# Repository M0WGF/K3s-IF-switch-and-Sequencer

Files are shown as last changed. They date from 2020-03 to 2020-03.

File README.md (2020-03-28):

# K3/s IF switch and Sequencer
Two port IF switch and three event sequencer for use with the Elecraft K3 and K3s transceivers. 

Switch between two external transverters directly from the Elecraft K3/s transceiver, the unit also comes with a three
port sequencer where the first event is for switching a relay and the last two events pull to ground.

The unit is based around an Arduino UNO see the .ino file for the script, it uses one no standard library which is
called Bounce2 and be downloaded from https://github.com/thomasfredericks/Bounce2

The unit has also been designed so that when the VSWR trip is pulled to ground the unit goes into a disabled state
stopping the transmitter and sounding a buzzer until the unit is reset. 

There are two boards the main board and an indicator board.  

The software has few parameters that can be changed look towards the top of the .ino file these are

// Event Sequence Delays 

int Sequence_Delay = 50; // Delay in milliseconds.
int Txinhibit_Delay = 50; 

// Default RX behaviour of events HIGH = On; LOW = Off.   Event 1 is capable of providing upto 28V 1A, and by default is 
set to energise the relay for RX.

int band0_event1 = HIGH;
int band0_event2 = LOW;
int band0_event3 = LOW;

int band1_event1 = HIGH;
int band1_event2 = LOW;
int band1_event3 = LOW;

// Debugging will output the debugs to the serial port. 
bool debug_main = false;

For further details see : 
https://m0wgf.blogspot.com/2019/12/dual-transverter-if-switch-and.html

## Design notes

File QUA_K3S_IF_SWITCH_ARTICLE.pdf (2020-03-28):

## A simple dual transverter IF switch and sequencers for the

Elecra9 K3S.

By Mark Horn M0WGF.
Interests in radio.

My main interest in amateur radio is in Earth-Moon-Earth (EME), Meteor Sca?er (MS), Machine Generated Modes(MGM) and the UKAC (UK Activity Contest) primarily on the 2m band as well as the 70cm band.

Consequently over the past few years I have been a?empting to build a high performance station built using a G4DDK transverters along with a HF transceiver to give the best performance I can afford on my budget.
Overview.

I have a medical condition called Muscular Dystrophy which results in the muscles of body slowly atrophying over Dme which has resulted in my hand muscles weakening to the point I struggle connecting and disconnecting any type of RF connector; this poses a problem in that I use transverters for my 2m and 70cm systems and constantly need to swap the 28MHz IF lines.

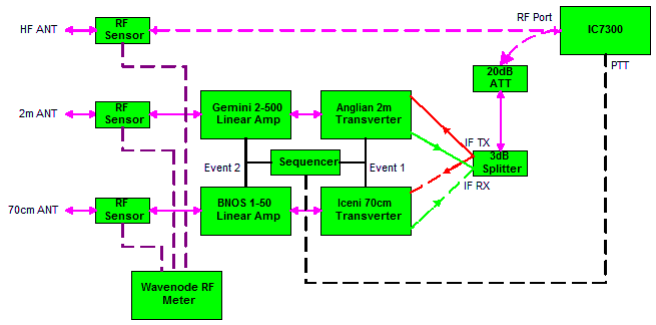
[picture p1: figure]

The original station configuration had the disadvantage in that the IF lines between the radio and transverter would need switching between transverters each Dme I wished change from 2m to 70cm. I also needed to unplug the HF antenna from the IC7300 and instead connect a 20dB a?enuator and 3dB spli?er to reduce the RF power down to around 0dBm and provide the RX / TX IF lines required by the transverter. Consequently each Dme I wanted to switch between either the transverters or the HF bands it felt like a major station configuration change.

Another issue with the IC7300 was geting a modulation that was free of spurii, this wasn’t an issue when using the transceiver on HF at 100W but when coupled with a transverter and high power amplifier the spurii in the adjacent 3kHz bandwidth or wider could be less than 40dB down in relation to the peak output.

I tried resolving this by using a modification by Kuhne electronics in Germany which places a small circuit board consisting of a couple of relays between the exciter and internal PA to provide TX and RX IF lines however the quality of modulation was still poor.

The main cause seems to be in the way Icom has implemented the ALC and acer reading reports from other operators it was apparent that geting the IC7300 to play nicely with any transverter varies from one IC7300 to another.

A station sequencer is employed to ensure any pre-amps are switched out of the TX signal path as well as to ensure hot switching doesn’t occur to any relays in said path before any RF is generated by the exciter by placing the exciter as the last event in the sequence.

The current setup used a single sequencer shared between the transverters and other devices though this was perfectly adequate I wanted the new system to use separate sequences where each event could be configured or at least modified at a later date without too much issue. It would also help if there was any RF leakage between adjacent relay contacts in the proposed IF switch wouldn’t be broadcast on the inactive band.

Both of my transverters where built with a single RF port with an internal relay to switch the port between the RX and TX ports on the transverter module however this isn’t ideal.

With EME we are dealing with path losses of around 250dB and as such the received signal is extremely weak so much so that you need to gain every decibel of receive performance you can, especially in a small system, even the losses incurred in multiple connectors and relays in the RX path can cause a dB or more of loss, with this in mind I also decided to modify both my transverters to provided a separate RX and TX RF ports.

The station also utilises an Wavenode RF power meter to monitor in real Dme the VSWR of each antenna. In the event of a high VSWR the Wavenode closes an internal relay this can used to connect to an external monitor to cease operation of the station.

So with the above in mind I decided to completely re-engineer the station to give the best receive and transmit performance I could get on the 2m and 70cm bands, reduce the amount of cable swapping and have separate sequencers for each of the transverters.

To cure the poor quality of the generated signal from the IC7300 I decided to sell it and instead purchase an Elecrac K3S (K3) instead.

The K3 helpfully provides both RX and TX IF ports with the TX port output at 0dBm giving the correct level of drive for the transverters.
A New Approach.

Upon reading the K3 manual I discovered the ACC port provides four TTL level, low (0V) or high (5V), logic gates where a combination of the four indicates which band is currently selected.

The ACC port can also provide PTT and TX inhibit functions again via two logic gates which would also reduce the amount of cabling required as well as ensure the all devices in the TX chain had switched fully before any RF is generated and vice versa for the RX chain.

The ACC port consists of a DE-15 socket where pins 3, 9, 13 and 14 provide access to the TTL logic gates and pins 7 and 10 provide the TX inhibit (TXINHIB), which can be configured to inhibit the exciter on either a high or low state, and KEYOUT-LP (PTT) which provides a 10mA sink to ground.

This was exactly what I needed to create a single control unit to switch IF lines, provide an independent sequencer to each transverter chain and to ensure that no RF was generated until all events in each sequence was completed all at the press of the band selector bu?on on the K3 acer some thought I came up with the following station configuration.

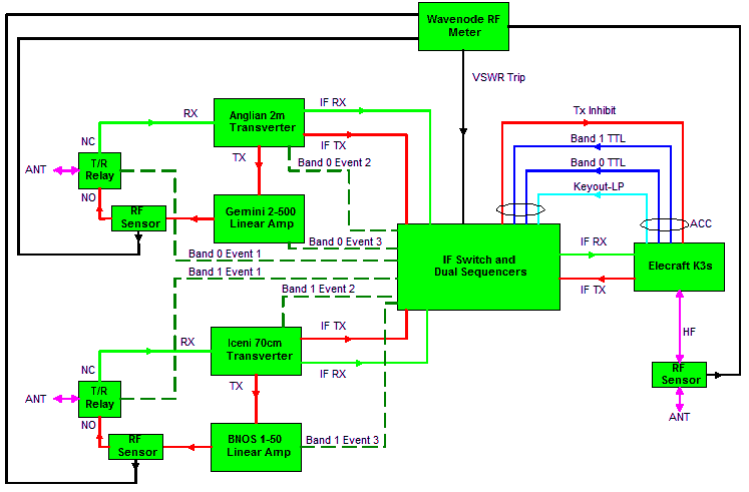
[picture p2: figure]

Hardware Configuration.

The K3s band logic gates can be configured in one of three ways NOR for HF bands only, TRN for transverters only and HF-TRN for both the HF bands and transverters. I selected the TRN seting which made reading the TTL logic simpler as it only requires knowing the current state of two of the logic gates instead of the four gates required for the NOR or HF-TRN configurations.

From here on forward when I reference bands it is taken to also include the transverters.

The band switch logic matrix for the K3 is shown lec.

As you can see from the table when TRN1 or TRN2 is selected the logic can either be on off for either band but they can neither be off or on together for band 0 and 1 so any other state would be equal to another band.

So with the above in mind I needed firstly someway to read the K3 TTL logic.

Secondly to key the 2m and 70cm transverters as well as associated amplifiers a 10mA sink to ground.

Thirdly the change over relays, Tohtsu CZX-3500, which require 12V and draw around 250mA, which would be held closed for RX operation and released for TX. The CZX-3500’s also have an advantage or providing an extra 20dB of isolation between ports compared to the ones in the transverters which only provided 40dB of isolation.

Fourthly the ability to control two mini relays to switch the IF lines between transverters.

Fichly It would also be useful to have some indication of which band has been selected as a separate confirmation to the K3, and that events for that band are being sequenced correctly.

Finally it would be nice to have some kind of audible alert in the event of a high VSWR.

ADDR | BAND0 | BAND1 | BAND2 | BAND3
TRN1 | 1 | 0 | 0 | 0
TRN2 | 0 | 1 | 0 | 0
TRN3 | 1 | 1 | 0 | 0
TRN4 | 0 | 0 | 1 | 0

Hardware and So9ware.

Thinking about how to go about accomplishing this I came to the conclusion using an Arduino microcontroller would be the easiest route to geting something working fairly quickly with li?le expense as well as keeping the electronics side of things simple.

The advantages using an Arduino :

1. Native ability to read the TTL logic from the K3.
2. General purpose I/O pins capable of providing or sinking 5V at 20mA.
3. Each I/O pin is protected from under and over voltage conditions using clamping diodes.

The Arduino UNO uses an ATMega328P which has 23 general purpose digital I/O pins available however two are used for serial coms and one for a reset bu?on, two pins are used for an external 16MHz crystal, so minus those five I/O pins eighteen pins are available to for other purposes.

I decided I need the following pins:

2 pins to read the band switch TTL logic from the K3.
3 pins to light LED’s to indicate which band has been selected on the unit. 2 pins for the IF relays.
1 pin to monitor PTT enabled from the K3.
1 pin for a PTT LED indicator.
1 pin to enable and disable TX Inhibit function on the K3.
1 pin to monitor the VSWR trip alert from the Wavenode RF power meter.
1 pin for the VSWR trip enabled warning buzzer.
1 pin for a VSWR trip reset bu?on, for which I’ll use the default Arduino reset pin. 6 pins for the two sets of three for the sequencer, one set for each band selected.

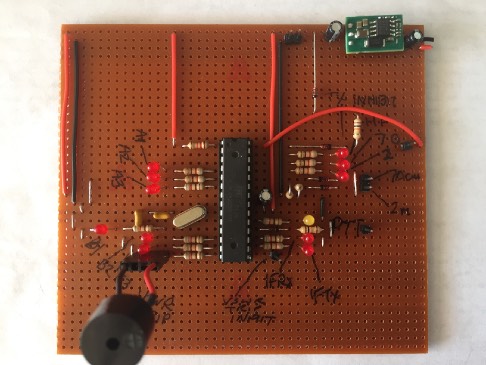
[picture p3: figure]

The first thing I did was to create a small prototype
board so I could write the socware and check
everything worked with the K3 before moving on to the
proper electronics, the purpose of the prototype board was to read the K3 TTL logic, show the state of the IF relays and sequencers using LED’s to indicate there current state as well test the TX inhibit function on the K3.

As is always the way with these things, having a shack that looks like a small nuke has gone off, I couldn’t find my breadboard to so had to make a test rig including an ATMega328 using some strip board instead this is also had the advantage that once it was wired up no amount
of moving it around on the desk the wiring will stay
error free.

Programming the Arduino is fairly straight forwarding using the Arduino IDE from the Arduino website¹. The language used is a subset of the C/C++ language which is fairly simple to use and there are plenty of resources on the internet to get you started.

The first iteration of the socware was a simple loop that read the state of the I/O pins that monitor the band logic gates on the K3 and lit an LED to indicate which transverter / band was selected.

What became apparent with this first simple loop was despite the fact there isn’t any mechanical switches the socware was experiencing contact bounce, also known as cha?er or bu?on bounce, seen in this instance as the wrong LED being lit for the band selected.

Contact bounce² is caused when a switch is pressed or released and for a few milliseconds or more the switch state is unstable to get around this problem it is normal to get the state of the I/O pin and store it in variable and then wait for a defined period and check

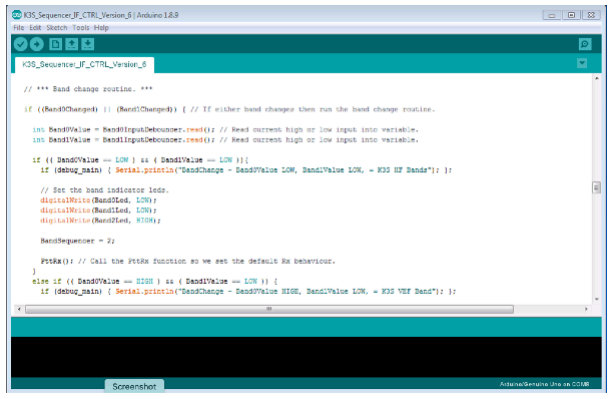
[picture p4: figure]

again when the stored state and current state are equal we can be sure the switch is either high or low.

There was two issues caused by contact bounce, one if the Arduino was switched on before the K3 then the band selected on the Arduino may not be in agreement with the band selected on the K3 and secondly when the band was changed on the K3 occasionally the wrong band was detected.

To resolve for these issues I started writing my own routine to take into account the unstable state of the switch while bouncing but in a sudden moment of genius decided not to reinvent the wheel and instead download and installed a library called Bounce2.h³ which reduced the amount of code I had to write for myself.

With the contact bounce cured it took an evening to write the socware⁴ and that included having to remind myself how hardware is referenced on the Arduino, the web is great for these kinds of projects there’s always plenty of example code around if you’re unsure how to do something.

With the socware wri?en the next thing to do was get on with the hardware, now electronics isn’t my forte so this wasn’t something I was looking forward too.

I knew for sequence events two and three some simple NPN transistors in low side configuration would suffice however for event one I needed the ability to switch between 5V to 48V drawing up to 1A, so that in the event I need to replace the change over relays I wouldn’t be restricted in what hardware could be used, so I chose to use a P-Channel MOSFET in a high side configuration.

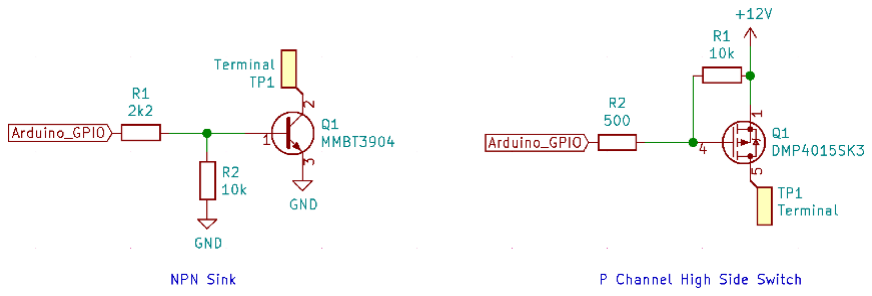
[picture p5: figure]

I had discussion with a friend who convinced me that isolating the high voltage side side of the circuit would be prudent, it’s not something I would have bothered with however opto-isolators are cheap as chips so I decided to isolate all of the sequencer events this would allow me to change the hardware configuration at a later date if I wanted to.

As I had moved to the opto-isolators I decided instead of turning the sequencer event indicator LED’s on direct from the ATMega I/O pins I would instead add an NPN switch in parallel to the opto-isolators to sink the LED cathodes to ground instead.

This seems to be overkill but as MMBT3904 NPN transistors are only five pence each including them wasn’t going to cost any significant amount and ensure if I altered the circuit later on I wouldn’t run foul of exceeding the 20mA limit on the ATMega I/O pins.

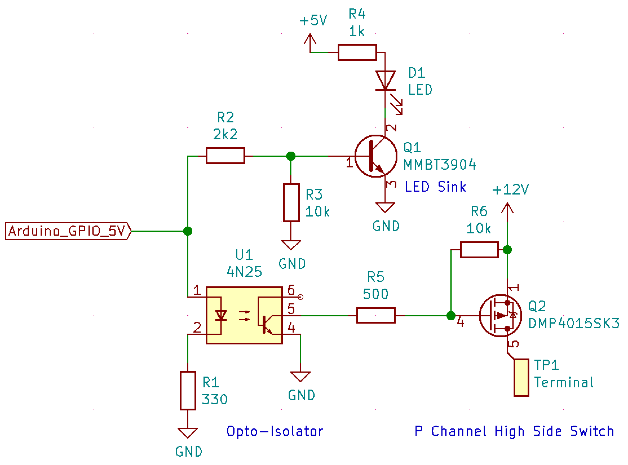
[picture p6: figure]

PCB Design and Manufacture.

With a general plan of action I decided instead of building the unit on strip board I would instead have ago at using KiCad⁵, to develop both the main PCB and front panel LED PCB.

KiCad is a cross plaoorm open source electronics design automation suite, which allows you create a circuit diagram of your design, perform the PCB layout and display a 3D rendition of the final product.

KiCad can also generate an LTSpice file from the circuit diagram as well which is handy if you wish to run a simulation of design.

KiCad, shown below, is fairly simple to use and there are a huge number of tutorials available on the internet. I will also be giving talk and demonstration at a CVRS club meeting early 2020.

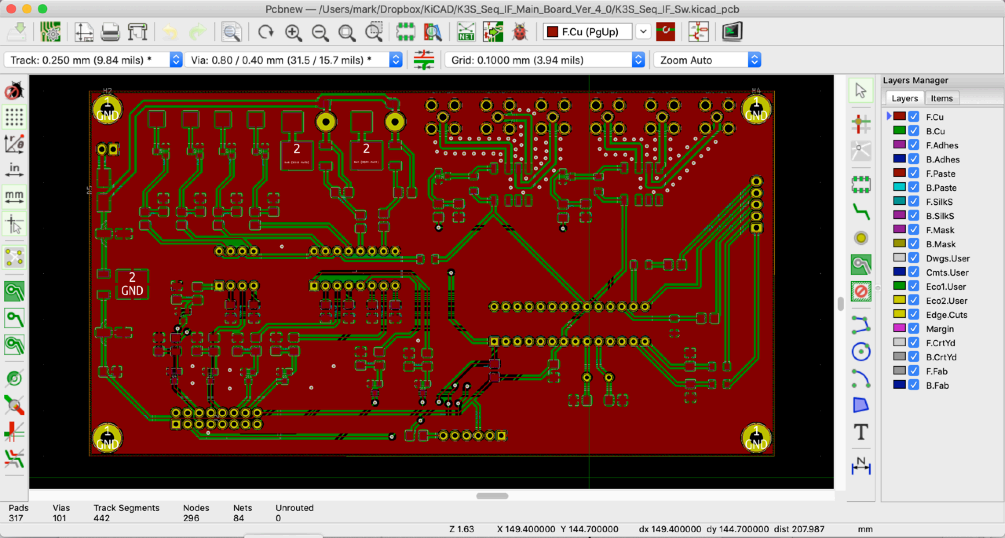
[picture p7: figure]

Below is full circuit diagram as created in KiCad.

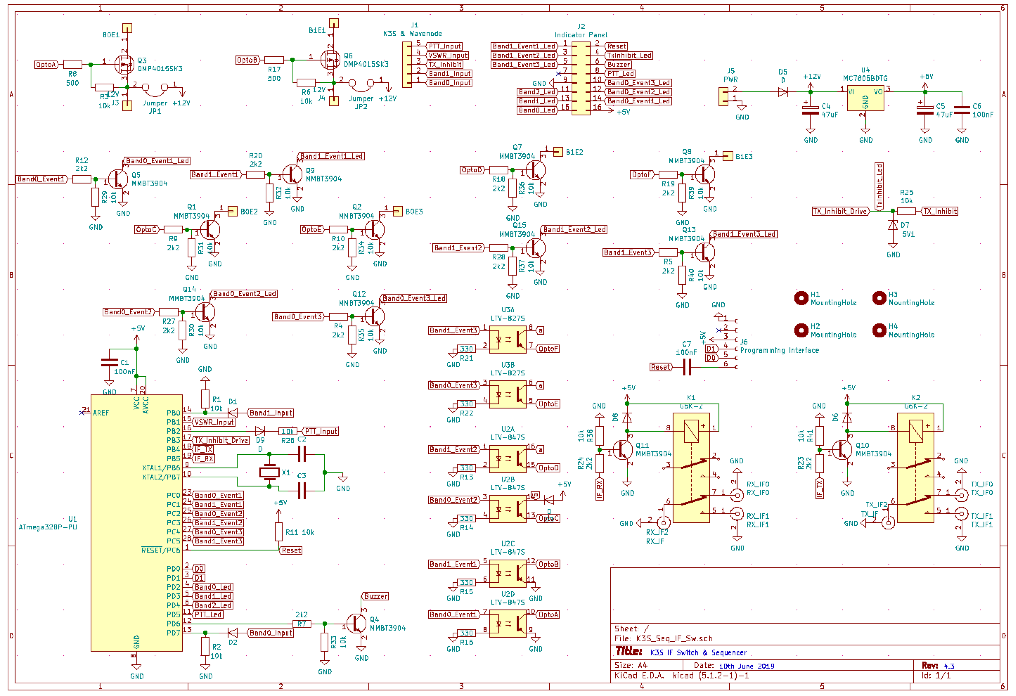
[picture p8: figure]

I decided to place all the LED indicators, high VSWR buzzer and reset bu?on on a small PCB, shown lec, which could then be mounted to the front of the case this removed a lot of wiring that would have been required if I had mount everything individually. I used IDC connectors to connect the two boards together which again made everything easy to plug and if for any reason there was a fault removing either board would only take a few moments to

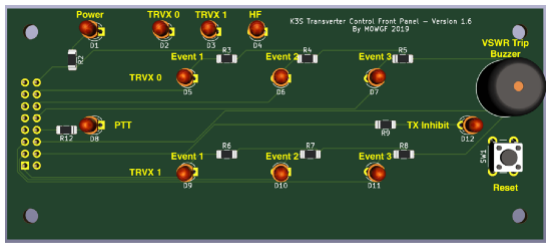
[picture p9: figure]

unplug the cables and pop the screws out. Shown below is the main board.

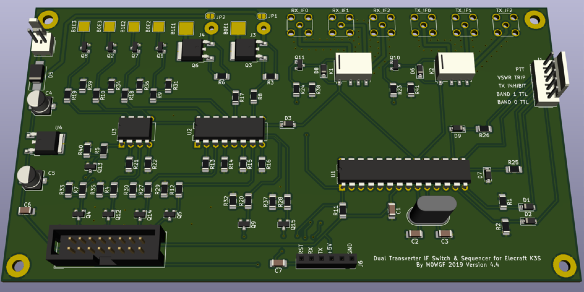
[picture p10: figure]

The PCB’s were manufactured by FirstPCB⁶, a Chinese company, they’re cheap to use in fact the postage costs more than the boards. You can however find cheaper manufactures but the Dme the boards take to come from China can take quite awhile as they’re normally sent surface mail instead of air mail. From the date of order they take two weeks to arrive they do give you the option of multiple carriers so you can pick from the cheapest offer available at the Dme of purchase.

The KiCad project files and Gerber files can be downloaded from Dropbox⁷. I do have a couple of sets of boards spare if anyone wants to build one of these units please drop me an email if interested.

Once the PCB’s had the boards had arrived and populated I mount the them in a Hammond ‘1550’ 275 x 175 x 67mm die cast enclosure which matched the transverters.

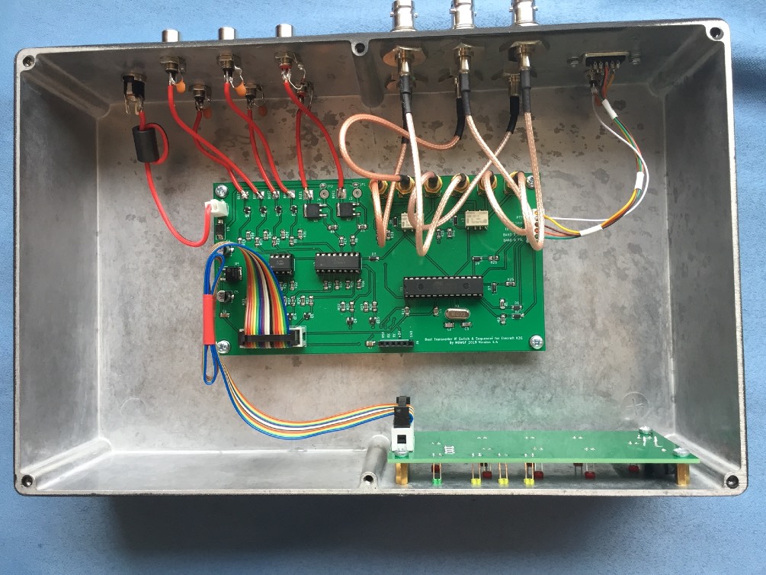
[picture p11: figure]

Hopefully this quick overview of this small project gives you some inspiration to create your own hardware or socware and create something that is tailored to your own needs.

1.) h?ps://www.arduino.cc/en/Main/socware (https://www.arduino.cc/en/Main/software)
2.) h?ps://en.wikipedia.org/wiki/Switch#Contact_bounce
3.) h?ps://github.com/thomasfredericks/Bounce2
4.) h?ps://www.dropbox.com/s/za1mdbixwdgjyzf/K3S_Sequencer_IF_CTRL_Version_6.zip?dl=0 5.) h?p://www.kicad-pcb.org
6.) h?ps://firstpcb.com
7.) h?ps://www.dropbox.com/s/n1fn1lh4imprqs1/K3s_Sequencer_IF_ProjectFiles.zip?dl=0

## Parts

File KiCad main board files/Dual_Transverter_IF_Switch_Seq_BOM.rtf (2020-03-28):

Dual Transverter IF Switch & Sequencer Version 4.3 BOM

R8, 17 - 100R 1206 - eBay £1.59 per 100 — 0.0318

R13, R14, R15, R16, R21, R22 - 330 1206 - eBay £1.59 per 100 - 0.0954

R1, R2, R3, R6, R11, R25, R26, R29, R30, R31, R32, R33, R34, R35, R36, R37, R38, R39, R40, R41 - 10k 1206 - eBay £1.59 per 100 - 0.318

R4, R5, R7, R9, R10, R12, R18, R19, R20, R23, R24, R27, R28 - 1k 1206 - eBay £1.59 per 100 - 0.2067

J1 - Molex KK-254 1x05 2.54mm Pitch - RS 483-8499 - £0.275 each

J2 - IDC Header 2x08 2.54mm Pitch - RS 625-7268 - £2.40 each

J5 - Molex KK-254 1x02 2.54mm Pitch - RS 483-8461 - £0.23 each

J6 - PinSocket 1x06 2.54mm Pitch - eBay £2.00 per 10 - 0.2

X1 - 16MHz HC49-U - RS 814-9440 - £0.17 each

C1, C6, C7 - 100nF 1206 - Enigma Store - £1.39 per 25 - 0.1668

C2, C3 - 22pF 1206 - Enigma Store - £0.89 per 25 - 0.0712

C4, C5 - 47uF Electrolytic - RS 537-0461 - £0.35 each - Total £0.70

D1, D2, D3, D6, D8, D9 - 1n4148 SOD-123 - RS 700-3671 - £0.095 each

D5 - 10BQ040 - RS 543-1566 - £0.48 each

D7 - 5V1 Zener SOD-123 - RS 545-3049 - £0.134 each

Q1, Q2, Q4, Q5, Q7, Q8, Q9, Q10, Q11, Q12, Q13, Q14, Q15 - MMBT3904 - RS 739-0303 - £0.018 each - Total £0.24

Q3, Q6 - DMP4015SK3 - RS 822-2643 - £0.652 each - Total £1.31

U1 - ATMega328P DIP-28 - RS 758-9339 - £4.13

U2 - LTV-847 DIP-16 - RS 691-2246 - £2.35 each

U3 - LTV827 DIP-8 - RS 691-2205 - £0.48 each

U4 - MC7805BDTH TO-252-2 - RS 688-9234 - £1.20 each

K1, K2 - G6K2FYDC5BYOMR - RS 807-4107 - £3.29 each - Total £6.58

SMA Sockets x 6 - RS 616-3422 - £1.94 each

£ 35.50 total per unit cost.

150 x 80
_________________________

MMBT3904 NPN
Vb = 0.7V
Ib = 5mA
Ic = 50mA

——————————————
PTT sink resistors
Base resistor = 1k
Base current = 4.3mA
Collector Current = 40mA
——————————————

6 x Opto LED 11.82mA = 70.92
9 x NPN 4.01mA = 36.09
1 x Diode + 10K 500uA = 110mA

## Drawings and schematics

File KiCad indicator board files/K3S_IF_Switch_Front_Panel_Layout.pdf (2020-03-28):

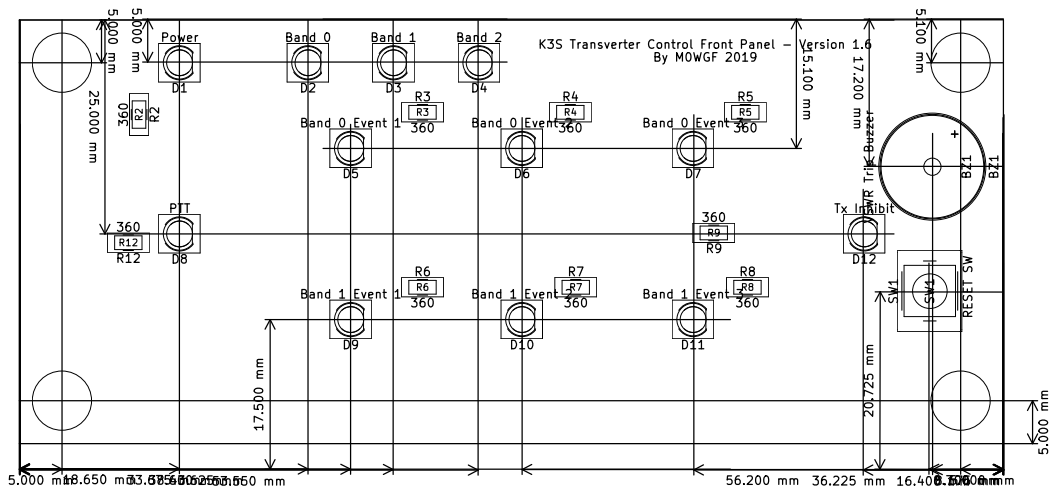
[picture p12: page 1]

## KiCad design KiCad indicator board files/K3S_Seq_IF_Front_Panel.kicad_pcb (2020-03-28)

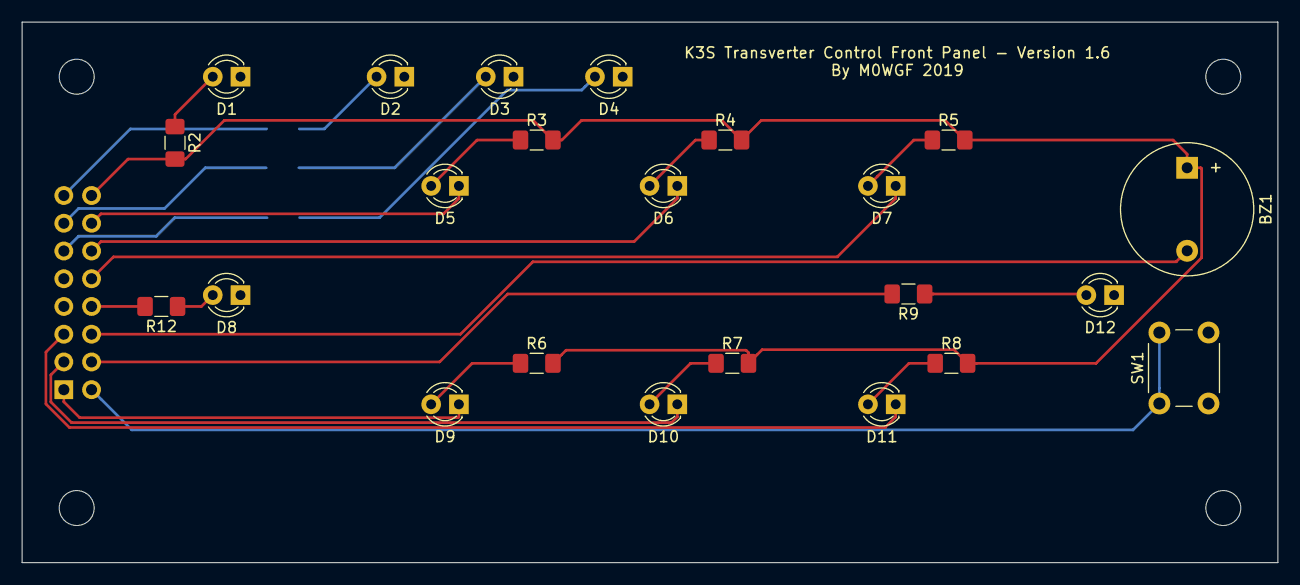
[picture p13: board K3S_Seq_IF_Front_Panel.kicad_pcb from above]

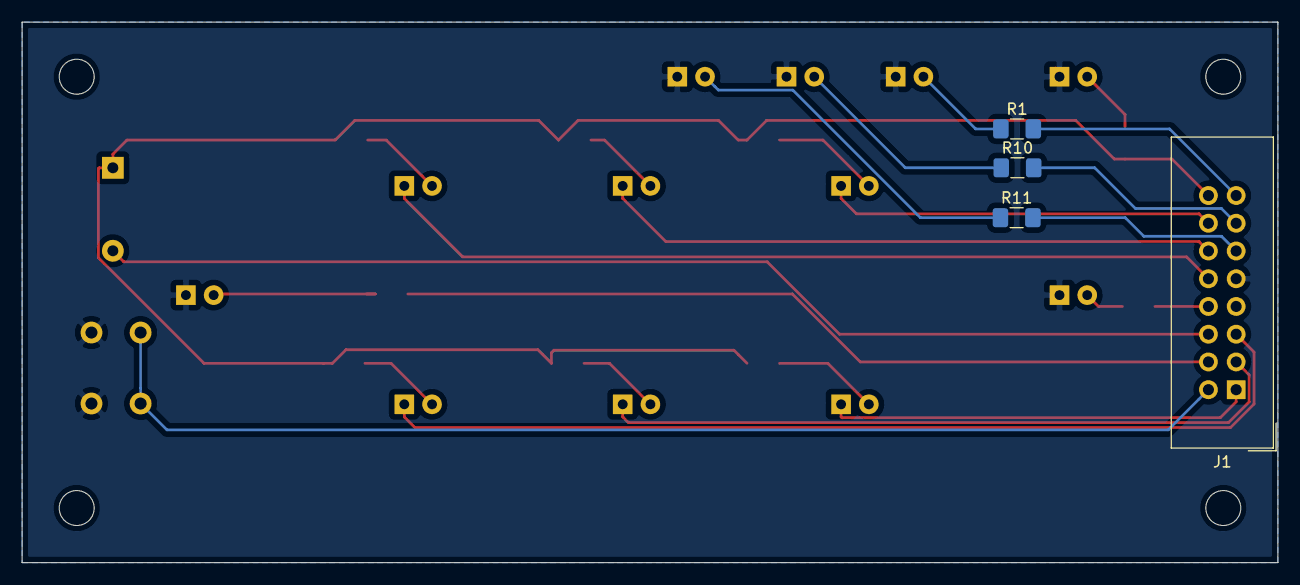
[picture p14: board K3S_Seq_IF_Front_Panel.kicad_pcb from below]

Board: 2 copper layers, 115.0 x 49.5 mm, 27 parts (4 on the bottom side), 27 nets.

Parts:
BZ1: VSWR Trip Buzzer; Buzzer_12x9.5RM7.6
D1: Power; LED_D3.0mm
D2: Band 0; LED_D3.0mm
D3: Band 1; LED_D3.0mm
D4: Band 2; LED_D3.0mm
D5: Band 0 Event 1; LED_D3.0mm
D6: Band 0 Event 2; LED_D3.0mm
D7: Band 0 Event 3; LED_D3.0mm
D8: PTT; LED_D3.0mm
D9: Band 1 Event 1; LED_D3.0mm
D10: Band 1 Event 2; LED_D3.0mm
D11: Band 1 Event 3; LED_D3.0mm
D12: Tx Inhibit; LED_D3.0mm
J1: Conn_02x08_Odd_Even; IDC-Header_2x08_P2.54mm_Vertical
R1, R2, R3, R4, R5, R6, R7, R8, R9, R10, R11, R12: 360; R_1206_3216Metric_Pad1.42x1.75mm_HandSolder
SW1: RESET SW; SW_PUSH_6mm

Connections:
+5V: BZ1.1, J1.16, R2.2, R3.2, R4.2, R5.2, R6.2, R7.2, R8.2
Band0_Event1_Led: D5.1, J1.14
Band0_Event2_Led: D6.1, J1.12
Band0_Event3_Led: D7.1, J1.10
Band0_Led: J1.15, R1.2
Band1_Event1_Led: D9.1, J1.1
Band1_Event2_Led: D10.1, J1.3
Band1_Event3_Led: D11.1, J1.5
Band1_Led: J1.13, R10.2
Band2_Led: J1.11, R11.2
Buzzer: BZ1.2, J1.6
GND: D1.1, D2.1, D3.1, D4.1, D8.1, D12.1, J1.9, SW1.2
unnamed: D1.2, R2.1
unnamed: D2.2, R1.1
unnamed: D3.2, R10.1
unnamed: D4.2, R11.1
unnamed: D5.2, R3.1
unnamed: D6.2, R4.1
unnamed: D7.2, R5.1
unnamed: D8.2, R12.1
unnamed: D9.2, R6.1
unnamed: D10.2, R7.1
unnamed: D11.2, R8.1
unnamed: D12.2, R9.1
PTT_Led: J1.8, R12.2
Reset: J1.2, SW1.1
TxInhibit_Led: J1.4, R9.2

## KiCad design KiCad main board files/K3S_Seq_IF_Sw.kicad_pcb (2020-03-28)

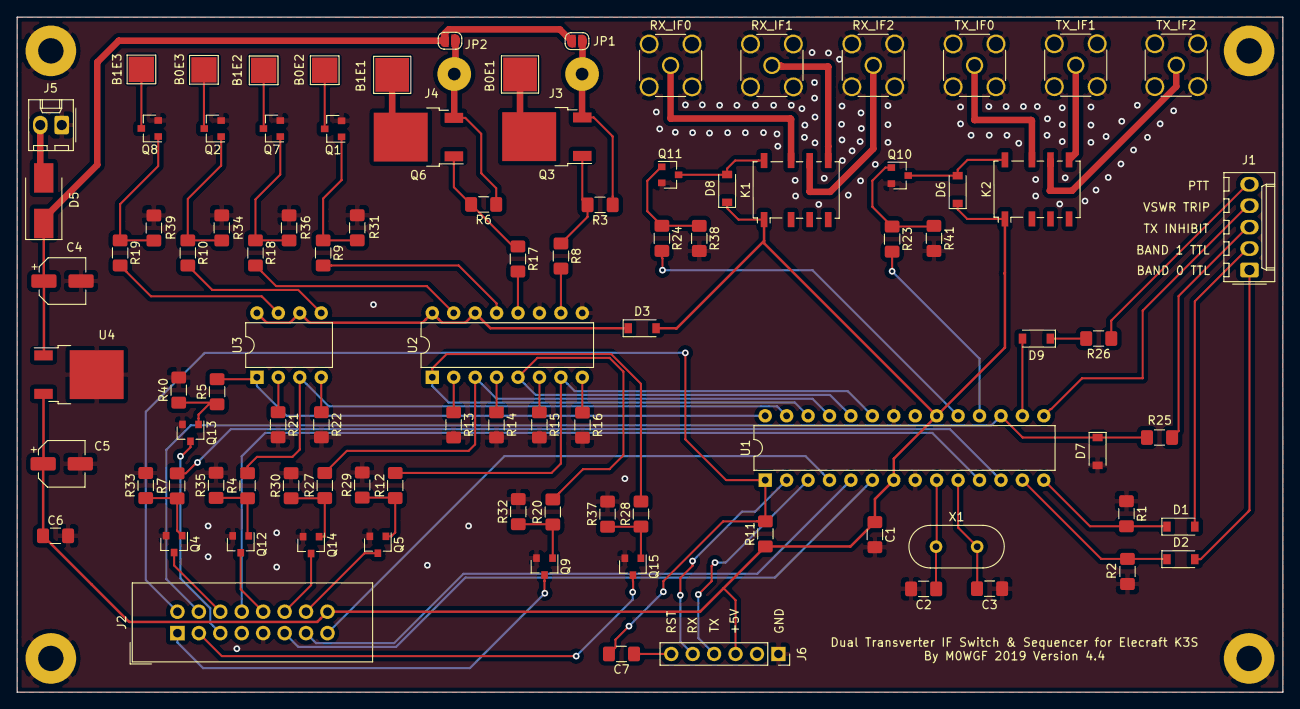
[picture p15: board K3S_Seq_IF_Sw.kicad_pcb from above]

Board: 2 copper layers, 150.0 x 80.0 mm, 102 parts (0 on the bottom side), 84 nets.

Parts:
B0E1, B1E1: Conn_01x01; TestPoint_Pad_4.0x4.0mm
B0E2, B0E3, B1E2, B1E3: Conn_01x01; TestPoint_Pad_3.0x3.0mm
C1, C6, C7: 100nF; C_1206_3216Metric_Pad1.42x1.75mm_HandSolder
C2, C3: 22pF; C_1206_3216Metric_Pad1.42x1.75mm_HandSolder
C4, C5: 47uF; CP_Elec_5x5.8
D1, D2, D3, D6, D8, D9: D; D_SOD-123
D5: D; D_SMB_Handsoldering
D7: 5V1; D_SOD-123
H1, H2, H3, H4: MountingHole; MountingHole_3mm_Pad
J1: K3S & Wavenode; Molex_KK-254_AE-6410-05A_1x05_P2.54mm_Vertical
J2: Indicator Panel; IDC-Header_2x08_P2.54mm_Vertical
J3, J4: 12V; SolderWirePad_1x01_Drill1.5mm
J5: PWR; Molex_KK-254_AE-6410-02A_1x02_P2.54mm_Vertical
J6: Programming Interface; PinSocket_1x06_P2.54mm_Vertical
JP1, JP2: Jumper; SolderJumper-2_P1.3mm_Open_RoundedPad1.0x1.5mm
K1, K2: G6K-2; Relay_DPDT_Omron_G6K-2F-Y
Q1, Q2, Q4, Q5, Q7, Q8, Q9, Q10, Q11, Q12, Q13, Q14, Q15: MMBT3904; SOT-23
Q3, Q6: DMP4015SK3; TO-252-2
R1, R2, R3, R6, R11, R25, R26, R29, R30, R31, R32, R33, R34, R35, R36, R37, R38, R39, R40, R41: 10k; R_1206_3216Metric_Pad1.42x1.75mm_HandSolder
R4, R5, R7, R9, R10, R12, R18, R19, R20, R23, R24, R27, R28: 2k2; R_1206_3216Metric_Pad1.42x1.75mm_HandSolder
R8, R17: 100; R_1206_3216Metric_Pad1.42x1.75mm_HandSolder
R13, R14, R15, R16, R21, R22: 330; R_1206_3216Metric_Pad1.42x1.75mm_HandSolder
RX_IF0: RX_IF0; SMA_Amphenol_132134-16_Vertical
RX_IF1: RX_IF1; SMA_Amphenol_132134-16_Vertical
RX_IF2: RX_IF; SMA_Amphenol_132134-16_Vertical
TX_IF0: TX_IF0; SMA_Amphenol_132134-16_Vertical
TX_IF1: TX_IF1; SMA_Amphenol_132134-16_Vertical
TX_IF2: TX_IF; SMA_Amphenol_132134-16_Vertical
U1: ATmega328P-PU; DIP-28_W7.62mm
U2: LTV-847S; DIP-16_W7.62mm
U3: LTV-827S; DIP-8_W7.62mm
U4: MC7805BDTG; TO-252-2
X1: Crystal; Crystal_HC49-U_Vertical

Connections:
+5V: C1.1, C5.1, C6.1, D3.2, D6.1, D8.1, J2.16, J6.3, K1.1, K2.1, R11.1, U1.7, U1.20, U4.3
+12V: C4.1, D5.1, JP1.1, JP2.1, U4.1
Band0_Event1: R12.2, U1.23, U2.7
Band0_Event1_Led: J2.14, Q5.3
Band0_Event2: R27.2, U1.25, U2.3
Band0_Event2_Led: J2.12, Q14.3
Band0_Event3: R4.2, U1.27, U3.3
Band0_Event3_Led: J2.10, Q12.3
Band0_Input: D2.2, J1.1
Band0_Led: J2.15, U1.4
Band1_Event1: R20.2, U1.24, U2.5
Band1_Event1_Led: J2.1, Q9.3
Band1_Event2: R28.2, U1.26, U2.1
Band1_Event2_Led: J2.3, Q15.3
Band1_Event3: R5.2, U1.28, U3.1
Band1_Event3_Led: J2.5, Q13.3
Band1_Input: D1.2, J1.2
Band1_Led: J2.13, U1.5
Band2_Led: J2.11, U1.6
Buzzer: J2.6, Q4.3
D0: J6.5, U1.2
D1: J6.4, U1.3
GND: C1.2, C2.2, C3.2, C4.2, C5.2, C6.2, D7.2, H1.1, H2.1, H3.1, H4.1, J2.9, J5.1, J6.1, Q1.2, Q2.2, Q4.2, Q5.2, Q7.2, Q8.2, Q9.2, Q10.2, Q11.2, Q12.2, Q13.2, Q14.2, Q15.2, R1.1, R2.2, R13.2, R14.2, R15.2, R16.2, R21.2, R22.2, R29.2, R30.2, R31.2, R32.2, R33.2, R34.2, R35.2, R36.2, R37.2, R38.2, R39.2, R40.2, R41.2, RX_IF0.2, RX_IF1.2, RX_IF2.2, TX_IF0.2, TX_IF1.2, TX_IF2.2, U1.8, U1.22, U2.9, U2.11, U4.2
IF_RX: R24.2, U1.19
IF_TX: R23.2, U1.18
unnamed: B0E1.1, Q3.2
unnamed: B0E2.1, Q1.3
unnamed: B0E3.1, Q2.3
unnamed: B1E1.1, Q6.2
unnamed: B1E2.1, Q7.3
unnamed: B1E3.1, Q8.3
unnamed: C2.1, U1.9, X1.1
unnamed: C3.1, U1.10, X1.2
unnamed: C7.1, J6.6
unnamed: D1.1, R1.2, U1.14
unnamed: D2.1, R2.1, U1.13
unnamed: D5.2, J5.2
unnamed: D6.2, K2.8, Q10.3
unnamed: D8.2, K1.8, Q11.3
unnamed: D9.1, R26.2
unnamed: D9.2, U1.16
unnamed: J3.1, JP1.2, Q3.3, R3.1
unnamed: J4.1, JP2.2, Q6.3, R6.1
unnamed: K1.5, RX_IF1.1
unnamed: K1.6, RX_IF2.1
unnamed: K1.7, RX_IF0.1
unnamed: K2.5, TX_IF1.1
unnamed: K2.6, TX_IF2.1
unnamed: K2.7, TX_IF0.1
unnamed: Q1.1, R9.1, R31.1
unnamed: Q2.1, R10.1, R34.1
unnamed: Q3.1, R3.2, R8.1
unnamed: Q4.1, R7.1, R33.1
unnamed: Q5.1, R12.1, R29.1
unnamed: Q6.1, R6.2, R17.1
unnamed: Q7.1, R18.1, R36.1
unnamed: Q8.1, R19.1, R39.1
unnamed: Q9.1, R20.1, R32.1
unnamed: Q10.1, R23.1, R41.1
unnamed: Q11.1, R24.1, R38.1
unnamed: Q12.1, R4.1, R35.1
unnamed: Q13.1, R5.1, R40.1
unnamed: Q14.1, R27.1, R30.1
unnamed: Q15.1, R28.1, R37.1
unnamed: R7.2, U1.12
unnamed: R13.1, U2.2
unnamed: R14.1, U2.4
unnamed: R15.1, U2.6
unnamed: R16.1, U2.8
unnamed: R21.1, U3.2
unnamed: R22.1, U3.4
OptoA: R8.2, U2.10
OptoB: R17.2, U2.12
OptoC: R9.2, U2.13
OptoD: R18.2, U2.15
OptoE: R10.2, U3.5
OptoF: R19.2, U3.7
PTT_Input: J1.5, R26.1
PTT_Led: J2.8, U1.11
Reset: C7.2, J2.2, R11.2, U1.1
TX_Inhibit: J1.3, R25.1
TX_Inhibit_Drive: D7.1, J2.4, R25.2, U1.17
VSWR_Input: J1.4, U1.15
a: D3.1, U2.14, U2.16, U3.6, U3.8

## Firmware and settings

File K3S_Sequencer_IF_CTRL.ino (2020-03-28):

/* 
 *  Elecraft K3 / K3S two port PTT Sequencer and TVRX IF Switch with VSWR Trip.
 *  Version : 06.0
 *  Author  : Mark Horn - M0WGF - mhorn71@gmail.com
 *  Date    : 2019
 *  
 * PTT Note :  My default PTT Rx action for event one on both band 0 and 1 to be high so the relay is energised for Rx and unenergised for Tx,
 *             to change set the required behaviour in Default RX Behaviour section below. 
 *             
 * K3S Setup :  K3IOB is set to 'trn' any other setting will not work correctly,  I have my 2m tvrx as trn1 and 70cm tvrx as trn2.
 *
 */ 
//  Version 4.3 I/O Pins.
//
//1   -- reset
//2
//3
//4   -- D2  ---- BAND 0 LED
//5   -- D3  ---- BAND 1 LED
//6   -- D4  ---- BAND 2 LED
//7   -- vcc
//8   -- gnd
//9   -- Xtal
//10  -- xtal
//11  -- D5  ---- PTT LED
//12  -- D6  ---- VSWR BUZZER
//13  -- D7  ---- BAND 0 INPUT
//14  -- D8  ---- BAND 1 INPUT
//15  -- D9  ---- VSWR TRIP INPUT
//16  -- D10 ---- PTT INPUT
//17  -- D11 ---- TX INHIBIT 
//18  -- D12 ---- IF TX 
//19  -- D13 ---- IF RX
//20  -- avcc
//21
//22  -- agnd
//23  -- a0 ---- BAND 0 EVENT 1 *
//24  -- a1 ---- BAND 1 EVENT 1 *
//25  -- a2 ---- BAND 0 EVENT 2 *
//26  -- a3 ---- BAND 1 EVENT 2 *
//27  -- a4 ---- BAND 0 EVENT 3 *
//28  -- a5 ---- BAND 1 EVENT 3 *
 
// https://github.com/thomasfredericks/Bounce2
#include <Bounce2.h>


// Event Sequence Delays

int Sequence_Delay = 50; // Delay in milliseconds.
int Txinhibit_Delay = 50; 

// Default RX behaviour of events HIGH = On; LOW = Off

int band0_event1 = HIGH;
int band0_event2 = LOW;
int band0_event3 = LOW;

int band1_event1 = HIGH;
int band1_event2 = LOW;
int band1_event3 = LOW;

// Debugging
bool debug_main = false;

// Band input pins.
#define Band0Input 7 // digital pin 7 when high band 0 enabled.
#define Band1Input 8 // digital pin 8 when high band 1 enabled.

// Instantiate a bounce objects for Band inputs.
Bounce Band0InputDebouncer = Bounce(); 
Bounce Band1InputDebouncer = Bounce();

// VSWR TRIP input pin.
#define VswrTripInput 9  // digital pin 9, pin low = vswr trip enabled.

// Instantiate a bounce object for vswr trip input.
Bounce VswrTripInputDebouncer = Bounce();

// PTT input pin.
#define PttInput 10 // digital pin 10, pin low = PTT enabled.

// Instantiate a bounce object for vswr trip input.
Bounce PttInputDebouncer = Bounce();

// TX inhibit pin.
#define TxInhibit 11  // digital pin 11, pin high = inhibit enabled, low = inhibit disabled.

// IF relays
#define TxIfOutput 12 // digital pin 12 when low IF TX band 0 enabled when high TX band 0 enabled.
#define RxIfOutput 13 // digital pin 13 when low IF RX band 0 enabled when high RX band 1 enabled.

// Sequencer event sinks.
#define Band0SequencerEvent1 A0  // digital pin A5 darlington pair can switch 12 or 24V.
#define Band0SequencerEvent2 A2  // digital pin A4 sinks 30mA to GND.
#define Band0SequencerEvent3 A4  // digital pin A3 sinks 30mA to GND.

#define Band1SequencerEvent1 A1  // digital pin A2 darlington pair can switch 12 or 24V.
#define Band1SequencerEvent2 A3  // digital pin A1 sinks 30mA to GND.
#define Band1SequencerEvent3 A5  // digital pin A0 sinks 30mA to GND.

// Band indicators.
#define Band0Led 2 // digital pin 2, pin high = 2m LED enabled.
#define Band1Led 3 // digital pin 3, pin high = 70cm LED enabled.
#define Band2Led 4 // digital pin 4, pin high = HF LED enabled.

// PTT indicator.
#define PttLed 5 // digital pin 5, pin high = TX LED enabled.

// VSWR trip buzzer.

#define VswrTripBuzzer 6  // digital pin 8, pin high = Buzzer enabled.

// Variables.
int BandSequencer = 0;   // Selected sequencer 0 - 2, 0 being VHF, 1 UHF and 2 HF where 2 bypasses sequenced events excluding tx inhibit. 
bool InitialBandSetup = true;  //  A simple trip so we set the inital band if we either turn or reset the K3S switcher unit after the K3S has been turned on.


void setup() {
  // Setup serial interface for debugging.
  Serial.begin(9600);
  
  // Attach the Band input debouncer instances 
  Band0InputDebouncer.attach(Band0Input,INPUT); 
  Band0InputDebouncer.interval(100); // Use a debounce interval of 25 milliseconds
  Band1InputDebouncer.attach(Band1Input,INPUT); 
  Band1InputDebouncer.interval(100); // Use a debounce interval of 25 milliseconds

  // Attach the VSWR TRIP input debounce instance
  VswrTripInputDebouncer.attach(VswrTripInput, INPUT_PULLUP);
  VswrTripInputDebouncer.interval(100);

  // Attach the PTT input debounce instance
  PttInputDebouncer.attach(PttInput, INPUT_PULLUP);
  PttInputDebouncer.interval(30);

  // pinMode Outputs.
  pinMode(TxInhibit, OUTPUT);
  
  pinMode(TxIfOutput, OUTPUT);
  pinMode(RxIfOutput, OUTPUT);
  
  pinMode(Band0SequencerEvent1, OUTPUT);
  pinMode(Band0SequencerEvent2, OUTPUT);
  pinMode(Band0SequencerEvent3, OUTPUT);

  pinMode(Band1SequencerEvent1, OUTPUT);
  pinMode(Band1SequencerEvent2, OUTPUT);
  pinMode(Band1SequencerEvent3, OUTPUT);

  pinMode(Band0Led, OUTPUT);
  pinMode(Band1Led, OUTPUT);
  pinMode(Band2Led, OUTPUT);

  pinMode(PttLed, OUTPUT);

  pinMode(VswrTripBuzzer, OUTPUT);

  // Set the TxInhibit default to HIGH so the K3S can't generate any RF to start with.
  digitalWrite(TxInhibit, HIGH);
  

}

void loop() {

  bool Band0Changed = Band0InputDebouncer.update(); // Update the Band0InputDebouncer instance 
  bool Band1Changed = Band1InputDebouncer.update(); // Update the Band1InputDebouncer instance

  if (InitialBandSetup) {
    
    Band0Changed = true; // Set one of the band changes to true to force a loop through the band change routine.
    InitialBandSetup = false; // Once we've done an inital loop we revert to normal behaviour of updating from Debouncer instance.
    
  }
  
  // *** Band change routine. *** 

  if ((Band0Changed) || (Band1Changed)) { // If either band changes then run the band change routine.

    int Band0Value = Band0InputDebouncer.read(); // Read current high or low input into variable.
    int Band1Value = Band1InputDebouncer.read(); // Read current high or low input into variable.

    if (( Band0Value == LOW ) && ( Band1Value == LOW )){
      if (debug_main) { Serial.println("BandChange - Band0Value LOW, Band1Value LOW, = K3S HF Bands"); };

      // Set the band indicator leds.
      digitalWrite(Band0Led, LOW);
      digitalWrite(Band1Led, LOW);
      digitalWrite(Band2Led, HIGH);
      
      BandSequencer = 2;

      PttRx(); // Call the PttRx function so we set the default Rx behaviour.
    }
    else if (( Band0Value == HIGH ) && ( Band1Value == LOW )) {
      if (debug_main) { Serial.println("BandChange - Band0Value HIGH, Band1Value LOW, = K3S VHF Band"); };

      // Set the band indicator leds.
      digitalWrite(Band0Led, HIGH);
      digitalWrite(Band1Led, LOW);
      digitalWrite(Band2Led, LOW);

      // Set the band IF relays to off for VHF band.
      digitalWrite(TxIfOutput, LOW);
      digitalWrite(RxIfOutput, LOW);
     
      BandSequencer = 0;

      PttRx(); // Call the PttRx function so we set the default Rx behaviour.
    }
    else if (( Band0Value == LOW ) && ( Band1Value == HIGH )) {
      if (debug_main) { Serial.println("BandChange - Band0Value LOW, Band1Value HIGH, = K3S UHF Band"); };

      // Set the band indicator leds.
      digitalWrite(Band0Led, LOW);
      digitalWrite(Band1Led, HIGH);
      digitalWrite(Band2Led, LOW);

      
      // Set the band IF relays to on for UHF band.
      digitalWrite(TxIfOutput, HIGH);
      digitalWrite(RxIfOutput, HIGH);
    
      BandSequencer = 1;

      PttRx(); // Call the PttRx function so we set the default Rx behaviour.
    }
  }

  // *** VSWR_TRIP change routine. ***

  VswrTripInputDebouncer.update();

  if ( VswrTripInputDebouncer.fell() ) {
    if (debug_main) { Serial.println("VSWR_TRIP has gone low so we need to cease all actions."); };

    VswrTrip();
    
  }

  // *** PTT change routine. ***

  PttInputDebouncer.update();

  if ( PttInputDebouncer.fell() ) {
    if (debug_main) { Serial.println("PTT has gone low so we need to call the sequencer routine for the appropriate band."); };

    PttTx();
    
  }
  else if ( PttInputDebouncer.rose() ) {
    if (debug_main) { Serial.println("PTT has gone high so we need to cease the sequencer routine for the appropriate band."); };

    PttRx();
    
  }

}

void VswrTrip(){

   if (debug_main) { Serial.println("VswrTrip called."); };

   PttRx();
  
   while (1) {  // Here we loop forever or until reset is called.
    digitalWrite(Band0Led, LOW);
    digitalWrite(Band1Led, LOW);
    digitalWrite(Band2Led, LOW);
    tone(VswrTripBuzzer, 1000);
    delay(500);
    digitalWrite(Band0Led, HIGH);
    digitalWrite(Band1Led, HIGH);
    digitalWrite(Band2Led, HIGH);
    noTone(VswrTripBuzzer);
    delay(500);
  }
}

void PttTx() {

  if (debug_main) { Serial.println("PttTx called."); };

  digitalWrite(PttLed, HIGH);
  
  if (BandSequencer == 0){
    // VHF
    if (debug_main) { Serial.println("PttTx BandSequence 0 - VHF."); };
    digitalWrite(Band0SequencerEvent1, !band0_event1);  // Change over relay is held high for tx so if we have a failure we default to the tx path.
    delay(Sequence_Delay);
    digitalWrite(Band0SequencerEvent2, !band0_event2); // when high the event transistor will sink 30mA.
    delay(Sequence_Delay);
    digitalWrite(Band0SequencerEvent3, !band0_event3); // when high the event transistor will sink 30mA.
    delay(Txinhibit_Delay);
    digitalWrite(TxInhibit, LOW);  // when low the K3S will all RF to be generated.
  }
  else if (BandSequencer == 1){
    // UHF
    if (debug_main) { Serial.println("PttTx BandSequence 1 - UHF."); };
    digitalWrite(Band1SequencerEvent1, !band1_event1);  // Change over relay is held low for tx so if we have a failure we default to the tx path.
    delay(Sequence_Delay);
    digitalWrite(Band1SequencerEvent2, !band1_event2); // when high the event transistor will sink 30mA.
    delay(Sequence_Delay);
    digitalWrite(Band1SequencerEvent3, !band1_event3); // when high the event transistor will sink 30mA.
    delay(Txinhibit_Delay);
    digitalWrite(TxInhibit, LOW);  // when low the K3S will all RF to be generated.
  }
  else if (BandSequencer == 2){
    // HF
    if (debug_main) { Serial.println("PttTx BandSequence 2 - HF."); };
    digitalWrite(TxInhibit, LOW);  // when low the K3S will all RF to be generated.
  }
}

void PttRx() {

  if (debug_main) { Serial.println("PttRx called."); };

  digitalWrite(PttLed, LOW);

  if (BandSequencer == 0){
    // VHF
    if (debug_main) { Serial.println("PttRx BandSequence 0 - VHF."); };
    digitalWrite(TxInhibit, HIGH);  // when high the K3S will not be able to generate RF.
    delay(Txinhibit_Delay);
    digitalWrite(Band0SequencerEvent3, band0_event3);   // when low the event transistor will cease sinking 30mA.
    delay(Sequence_Delay);
    digitalWrite(Band0SequencerEvent2, band0_event2);   // when low the event transistor will cease sinking 30mA.
    delay(Sequence_Delay);
    digitalWrite(Band0SequencerEvent1, band0_event1);  // Change over relay is held low for rx so if we have a failure we default to the tx path.

    if (band0_event1 == HIGH) {
      digitalWrite(Band1SequencerEvent1, LOW);   // Do the opposite action for Band 1 Event 1 otherwise both leds will be which would be visually confusing.
    }
  }
  else if (BandSequencer == 1){
    // UHF
    if (debug_main) { Serial.println("PttRx BandSequence 1 - UHF."); };
    digitalWrite(TxInhibit, HIGH);  // when high the K3S will not be able to generate RF.
    delay(Txinhibit_Delay);
    digitalWrite(Band1SequencerEvent3, band1_event3);   // when low the event transistor will cease sinking 30mA.
    delay(Sequence_Delay);
    digitalWrite(Band1SequencerEvent2, band1_event2);   // when low the event transistor will cease sinking 30mA.
    delay(Sequence_Delay);
    digitalWrite(Band1SequencerEvent1, band1_event1);  // Change over relay is held low for rx so if we have a failure we default to the tx path.

    /* As I have event1 on both band 0 & 1 high this looks confusing so I switch the unused bands event 1 to off, remember to
       comment this line out if the default current band event 1 is low.
    */

    if (band1_event1 == HIGH) {
      digitalWrite(Band0SequencerEvent1, LOW);   // Do the opposite action for Band 0 Event 1 otherwise both leds will be which could be visually confusing.
    }
  }
  else if (BandSequencer == 2){
    // HF
    if (debug_main) { Serial.println("PttRx BandSequence 2 - HF."); };
    digitalWrite(TxInhibit, HIGH);  // when high the K3S will not be able to generate RF.
    
    /* As I have event1 on both band 0 & 1 high this looks confusing so I switch the unused bands event 1 to off, remember to
       comment this line out if the default current band event 1 is low.
    */

    // Set all Band 1 events to off otherwise visually it could be confusing.
    digitalWrite(Band1SequencerEvent1, LOW);
    digitalWrite(Band1SequencerEvent2, LOW);
    digitalWrite(Band1SequencerEvent3, LOW);

    // Set all Band 0 events to off otherwise visually it could be confusing.
    digitalWrite(Band0SequencerEvent1, LOW);
    digitalWrite(Band0SequencerEvent2, LOW);
    digitalWrite(Band0SequencerEvent3, LOW);   
  }  
 
}

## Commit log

2020-03-28 Added KiCad files and Gerber files.
    [K3S_Seq_IF_Sw-B_Cu.gbr, K3S_Seq_IF_Sw-B_Mask.gbr, K3S_Seq_IF_Sw-B_Paste.gbr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]
2020-03-28 Renamed the initial folder names so we can add the front display board stuff in awhile.
    [K3S_Seq_IF_Sw-B_Cu.gbr, K3S_Seq_IF_Sw-B_Mask.gbr, K3S_Seq_IF_Sw-B_Paste.gbr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]
2020-03-28 First commit of the Arduino script.
2020-03-28 First commit of the indicator board and gerbers
    [K3S_Seq_IF_Front_Panel-B_Cu.gbr, K3S_Seq_IF_Front_Panel-B_Mask.gbr, K3S_Seq_IF_Front_Panel-B_SilkS.gbr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]
